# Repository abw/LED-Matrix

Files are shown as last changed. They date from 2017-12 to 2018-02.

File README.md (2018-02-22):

# LED-Matrix
This project contains design templates, schematics, PCB layouts and
other resources for the construction of an LED Matrix

Watch the YouTube video series:

* [Part 1](https://www.youtube.com/watch?v=AXzYg67qcFU)
* [Part 2](https://www.youtube.com/watch?v=oouwt-w1FjE)
* [Part 3](https://www.youtube.com/watch?v=P1SUvm24y38)
* [Part 4](https://www.youtube.com/watch?v=9LTRPMgsqeI)

The [documents](documents) directory contains plans, templates, cutting
guides, etc.

See the [hardware](hardware) directory for the
schematics and board designs for the [power distribution board](hardware/Power%20Board/v1.2)
and the main [control board](hardware/Control%20Board/v1.0).

The [arduino](arduino) directory contains the source code for Arduino firmware.
This includes the examples that are shown in part 4 of the video series.

The [sketchup](sketchup) directory contains a CAD design of the LED
Matrix created in Sketchup.

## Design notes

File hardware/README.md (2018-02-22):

# LED-Matrix Hardware
This directory contains the Eagle schematics, board designs and Gerber
files for the LED Matrix.

The [Power Board](Power%20Board/v1.2) is a power distribution module
that hosts 3 MP1584EN buck regulator modules.  These provide power for
the LED strips.

The [Control Board](Control%20Board/v1.0) is a board which can be used
as an all-in-one Arduino shield, or as a pair of mother/daughter boards.
It provides a connection to the Power Board to receive power and return
data for the LED strips.  It also has 4 connectors for push-button
switches with integrated LEDs in the bezel.

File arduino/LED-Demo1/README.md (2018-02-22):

# LED-Demo1

This is the first "proper" attempt at writing some pattern generation
firmware for the 24x18 LED Matrix.

At the time of writing (22th Feb 2018) this code is still very much a
work in progress.

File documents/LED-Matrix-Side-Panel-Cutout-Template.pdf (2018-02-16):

LED Matrix - Side Panel Cutout Template

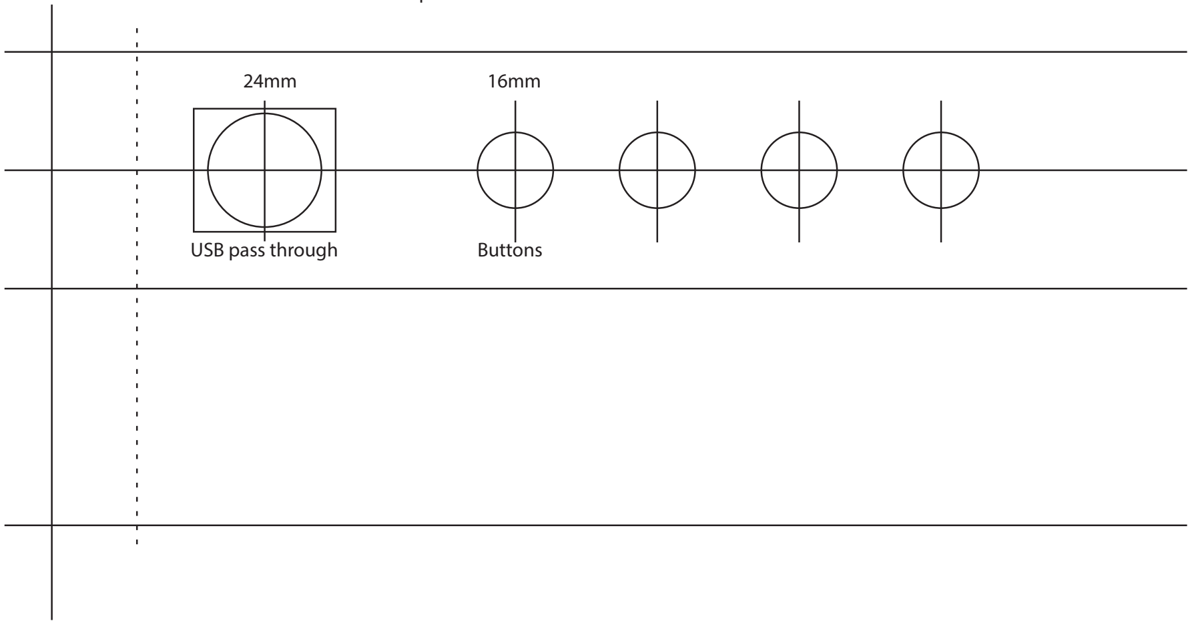
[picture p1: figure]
USB pass through; Buttons

Andy Wardley - December 2017

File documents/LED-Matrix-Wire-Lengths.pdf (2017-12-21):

### LED Matrix - wire lengths for connecting LED strips to power distribution boards

X | 100 | horizontal distance between connectors and power board
Y | 33.333 | vertical distance between each row of LEDs (30/m = 1000mm/30 = 33.333mm)
DY | 9 | vertical distance between connectors (9mm)
Margin | 20
| | Connectors for strips are labelled: A B C D E F with power board between C and D
A,F | 180.8325 | X + 2.5(Y - DY) + Margin
B,E | 156.4995 | X + 1.5(Y - DY) + Margin
C,D | 132.1665 | X + 0.5(Y - DY) + Margin

1

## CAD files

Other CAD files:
sketchup/LED-Matrix-case.skp

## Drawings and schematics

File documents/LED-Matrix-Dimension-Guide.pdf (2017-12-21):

## CUT-AWAY SIDE VIEW

## LED Matrix Dimension Guide

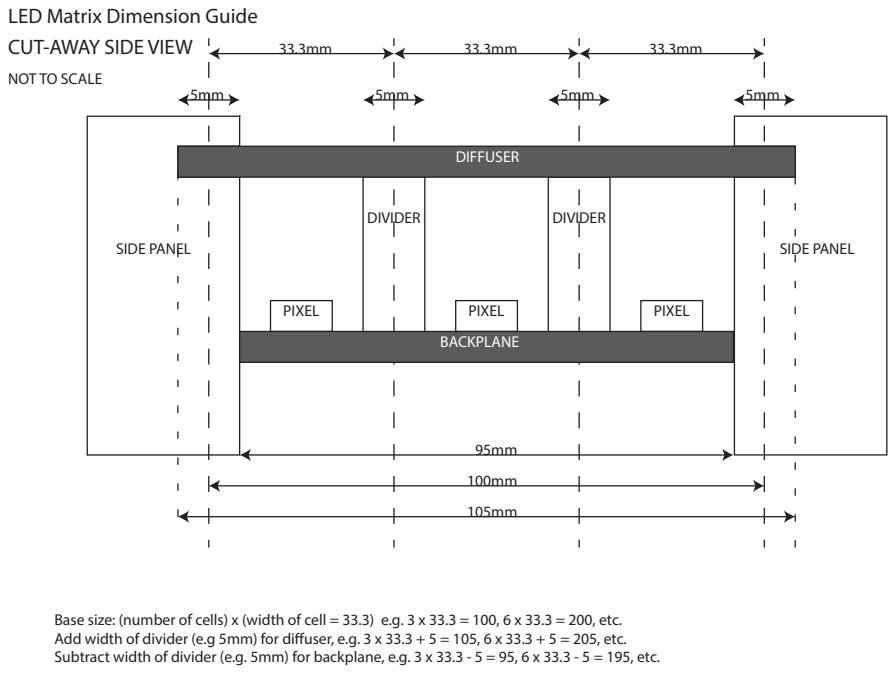
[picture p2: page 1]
BACKPLANE; DIFFUSER; SIDE PANEL; DIVIDER; PIXEL

NOT TO SCALE

Base size: (number of cells) x (width of cell = 33.3) e.g. 3 x 33.3 = 100, 6 x 33.3 = 200, etc.
Add width of divider (e.g 5mm) for diuser, e.g. 3 x 33.3 + 5 = 105, 6 x 33.3 + 5 = 205, etc.
Subtract width of divider (e.g. 5mm) for backplane, e.g. 3 x 33.3 - 5 = 95, 6 x 33.3 - 5 = 195, etc.

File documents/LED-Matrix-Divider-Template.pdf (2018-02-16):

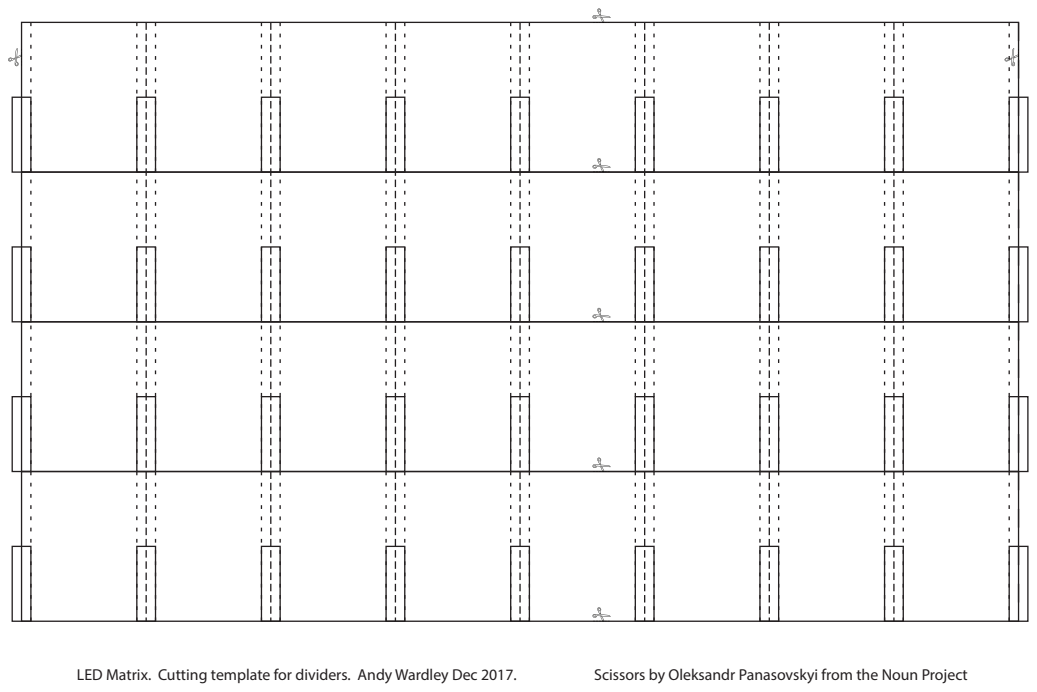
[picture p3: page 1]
LED Matrix. Cutting template for dividers. Andy Wardley Dec 2017.; Scissors by Oleksandr Panasovskyi from the Noun Project

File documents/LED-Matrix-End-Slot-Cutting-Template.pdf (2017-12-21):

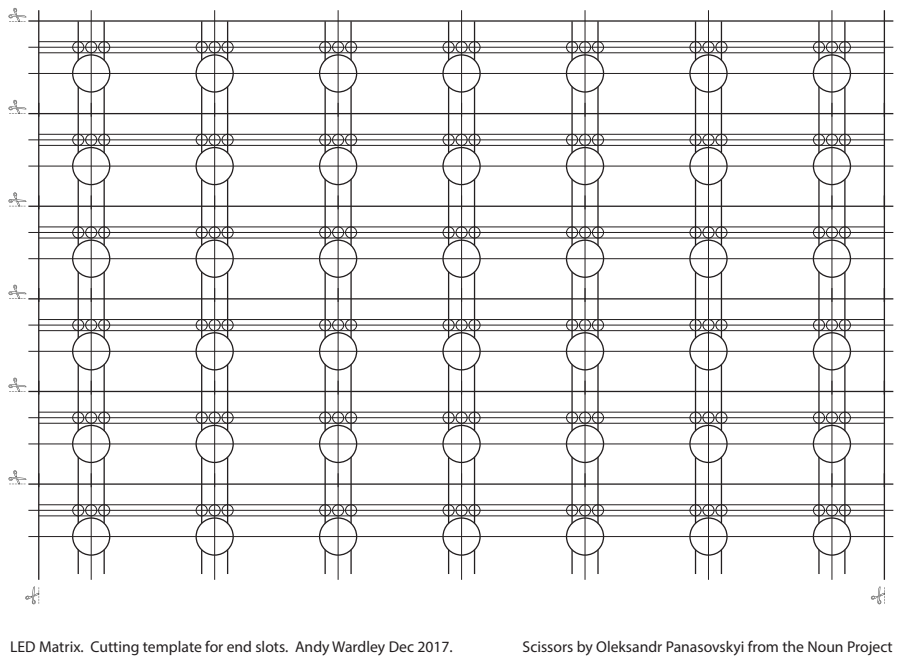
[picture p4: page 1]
LED Matrix. Cutting template for end slots. Andy Wardley Dec 2017.; Scissors by Oleksandr Panasovskyi from the Noun Project

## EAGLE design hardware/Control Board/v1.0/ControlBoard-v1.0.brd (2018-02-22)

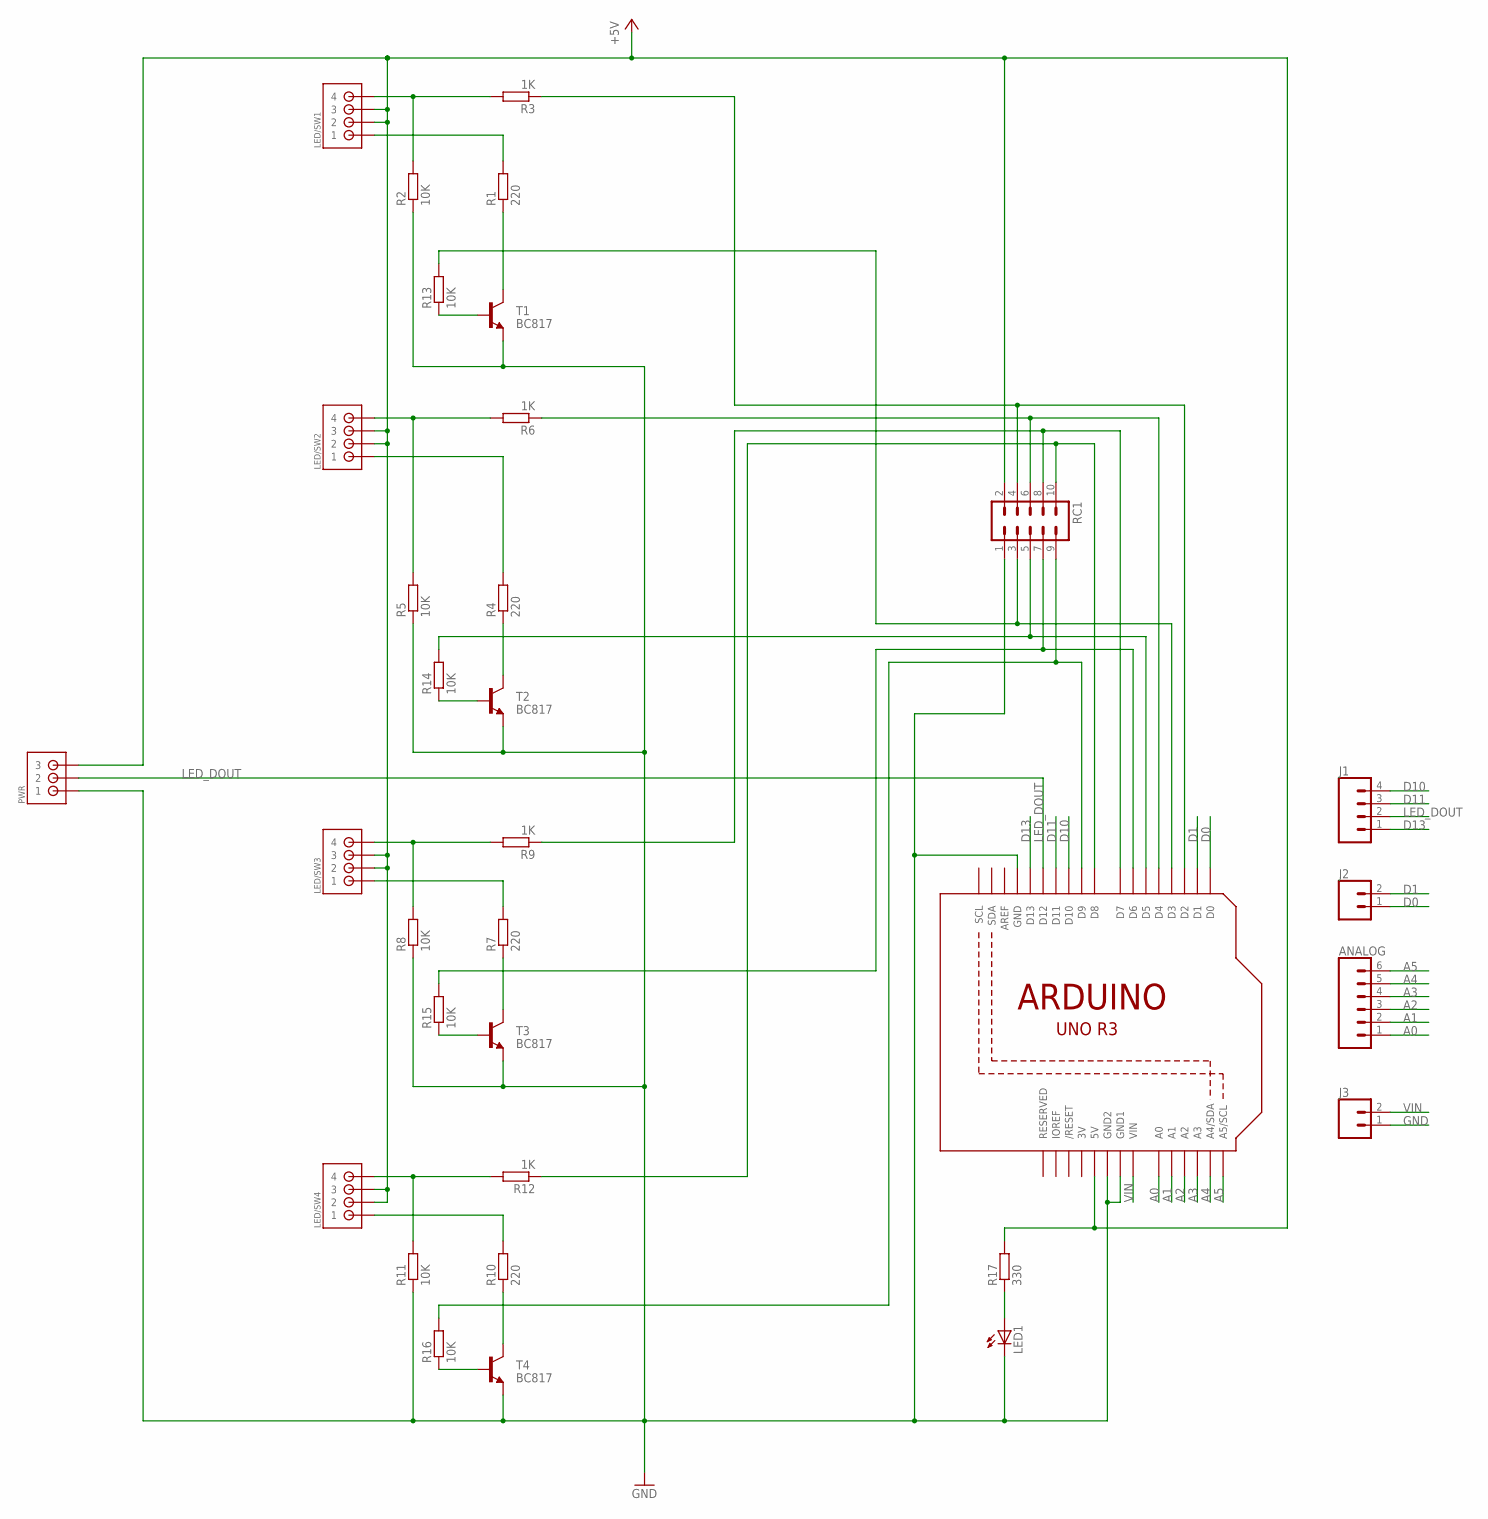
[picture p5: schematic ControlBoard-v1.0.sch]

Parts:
ANALOG: CONN_06SILK_FEMALE_PTH; 1X06
J1: CONN_04; 1X04
J2, J3: CONN_02; 1X02
LED1: LEDCHIPLED_0805; CHIPLED_0805
LED/SW1, LED/SW2, LED/SW3, LED/SW4: JST-XA-04-PIN; JST-XA-04
PWR: JST-XA-03-PIN; JST-XA-03
R1, R4, R7, R10: 220; R0805
R2, R5, R8, R11, R13, R14, R15, R16: 10K; R0805
R3, R6, R9, R12: 1K; R0805
R17: 330; R0805
RC1: ML10
T1, T2, T3, T4: BC817; SOT23
U1: ARDUINO-SHIELDLET; ARDUINOR3-PINS

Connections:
3V: U1.3V
+5V: LED/SW1.2, LED/SW1.3, LED/SW2.2, LED/SW2.3, LED/SW3.2, LED/SW3.3, LED/SW4.2, LED/SW4.3, PWR.3, R17.2, RC1.2, U1.5V
A0: ANALOG.1, U1.A0
A1: ANALOG.2, U1.A1
A2: ANALOG.3, U1.A2
A3: ANALOG.4, U1.A3
A4: ANALOG.5, U1.A4 (A4/SDA)
A5: ANALOG.6, U1.A5 (A5/SCL)
D0: J2.1, U1.D0
D1: J2.2, U1.D1
D10: J1.4, U1.D10
D11: J1.3, U1.D11
D13: J1.1, U1.D13
GND: J3.1, LED1.C, PWR.1, R2.1, R5.1, R8.1, R11.1, RC1.1, T1.2 (E), T2.2 (E), T3.2 (E), T4.2 (E), U1.GND, U1.GND1, U1.GND2
LED_DOUT: J1.2, PWR.2, U1.D12
unnamed: LED/SW1.1, R1.2
unnamed: R1.1, T1.3 (C)
unnamed: LED/SW1.4, R2.2, R3.2
unnamed: R3.1, RC1.4, U1.D2
unnamed: R13.1, T1.1 (B)
unnamed: LED/SW2.1, R4.2
unnamed: R4.1, T2.3 (C)
unnamed: LED/SW2.4, R5.2, R6.2
unnamed: R6.1, RC1.6, U1.D4
unnamed: R14.2, RC1.5, U1.D5
unnamed: LED/SW3.1, R7.2
unnamed: R7.1, T3.3 (C)
unnamed: LED/SW3.4, R8.2, R9.2
unnamed: R9.1, RC1.8, U1.D7
unnamed: R15.2, RC1.7, U1.D6
unnamed: LED/SW4.1, R10.2
unnamed: R10.1, T4.3 (C)
unnamed: LED/SW4.4, R11.2, R12.2
unnamed: R12.1, RC1.10, U1.D8
unnamed: R16.2, RC1.9, U1.D9
unnamed: R14.1, T2.1 (B)
unnamed: R15.1, T3.1 (B)
unnamed: R16.1, T4.1 (B)
unnamed: LED1.A, R17.1
unnamed: R13.2, RC1.3, U1.D3
VIN: J3.2, U1.VIN

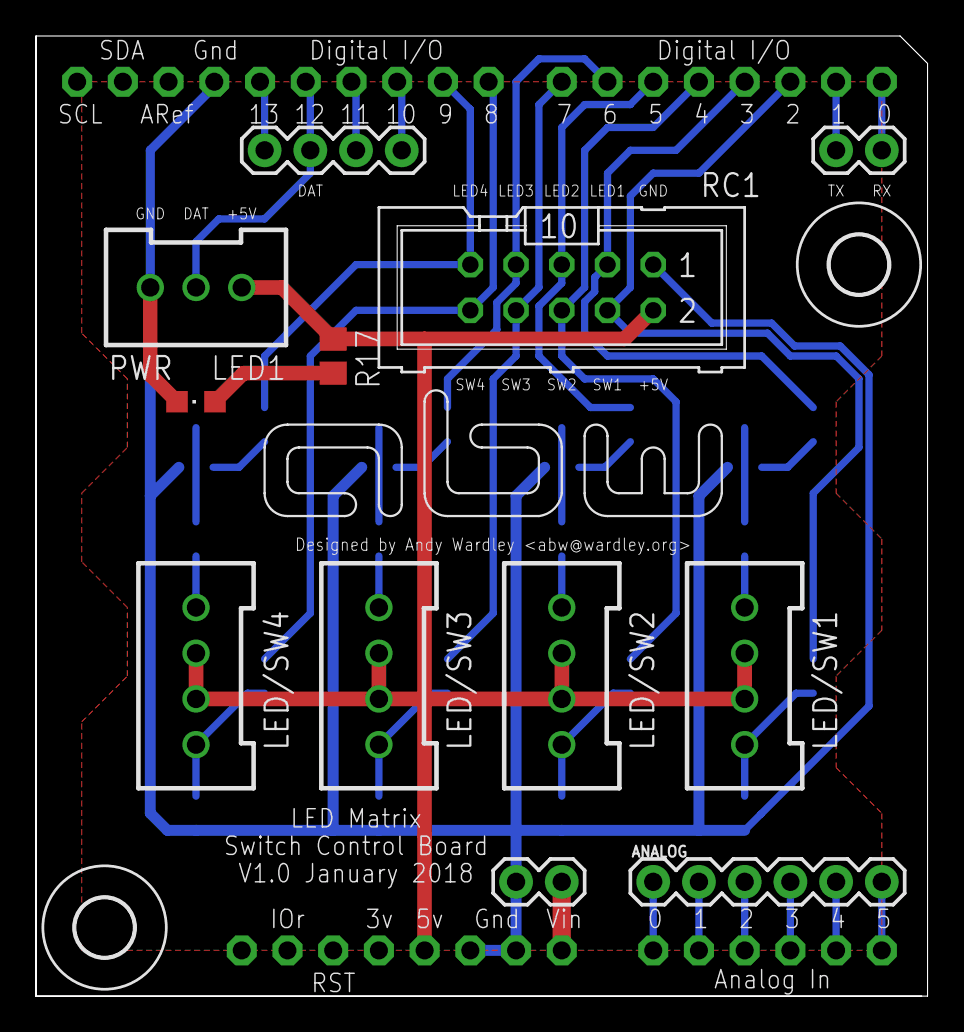
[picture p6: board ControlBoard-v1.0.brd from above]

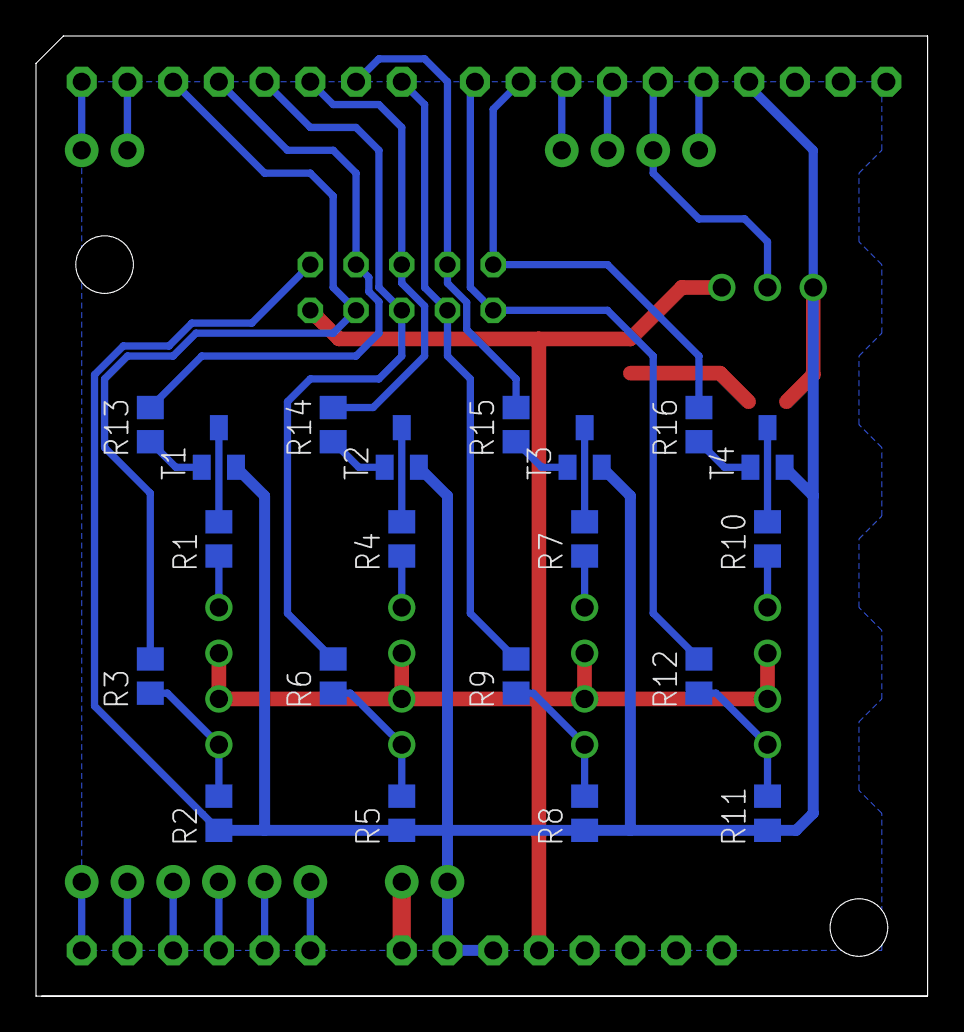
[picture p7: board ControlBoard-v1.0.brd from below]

Board: 2 copper layers, 49.5 x 53.3 mm, 36 parts (20 on the bottom side), 40 nets.

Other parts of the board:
U$2, U$3: 3,2
U$4: ABWLOGO-TINY

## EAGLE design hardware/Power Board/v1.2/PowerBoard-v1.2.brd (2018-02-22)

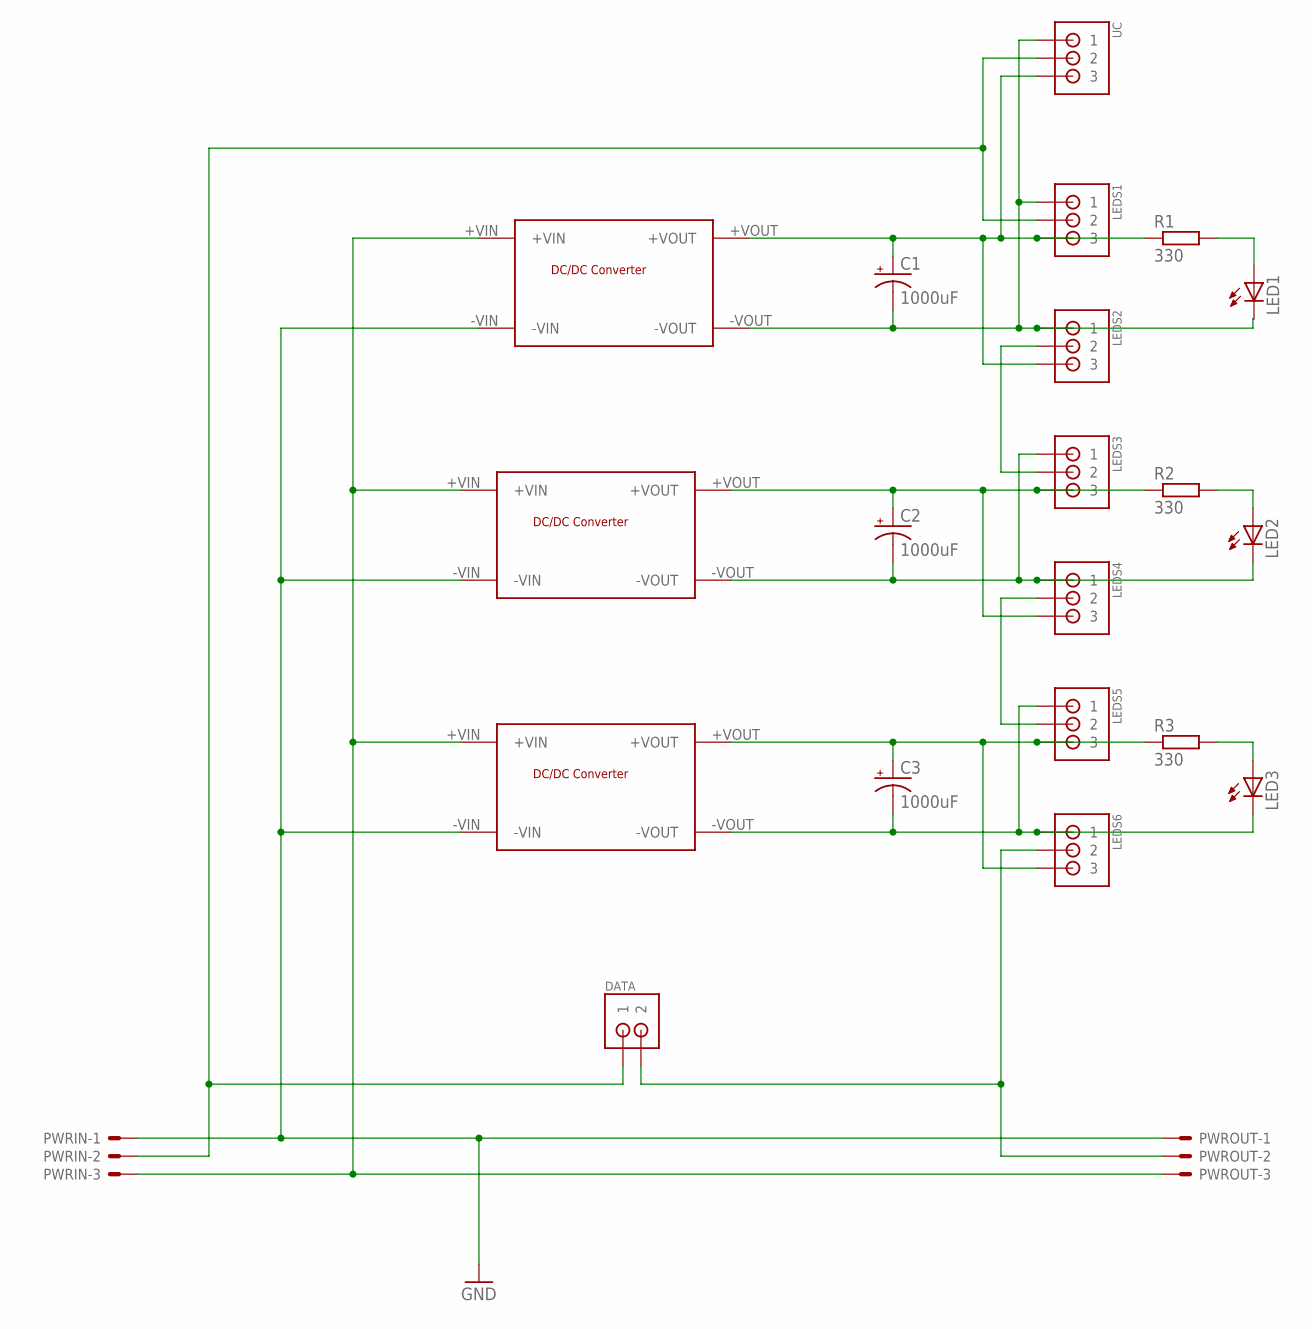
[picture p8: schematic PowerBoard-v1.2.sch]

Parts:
C1, C2, C3: 1000uF; CPOL-RADIAL-1000UF-25V
DATA: JST-XA-02-PIN; JST-XA-02
LED1, LED2, LED3: LEDCHIP-LED0805; CHIP-LED0805
LEDS1, LEDS2, LEDS3, LEDS4, LEDS5, LEDS6: JST-XA-03-PIN; JST-XA-03
PWRIN: KK-156-3
PWROUT: KK-156-3
R1, R2, R3: 330; M0805
U$1, U$2, U$3: DC-DC-CONVERTER; MP1584EN-BUCK-CONVERTER
UC: JST-XA-03-PIN; JST-XA-03

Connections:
DATIN: DATA.1, LEDS1.2, PWRIN.2, UC.2
DATOUT: DATA.2, LEDS6.2, PWROUT.2
GND: PWRIN.1, PWROUT.1, U$1.-VIN, U$2.-VIN, U$3.-VIN
GNDOUT1: C1.-, LED1.C, LEDS1.1, LEDS2.1, U$1.-VOUT, UC.1
GNDOUT2: C2.-, LED2.C, LEDS3.1, LEDS4.1, U$2.-VOUT
GNDOUT3: C3.-, LED3.C, LEDS5.1, LEDS6.1, U$3.-VOUT
unnamed: LED1.A, R1.2
unnamed: LED2.A, R2.2
unnamed: LEDS2.2, LEDS3.2
unnamed: LEDS4.2, LEDS5.2
unnamed: LED3.A, R3.2
VIN: PWRIN.3, PWROUT.3, U$1.+VIN, U$2.+VIN, U$3.+VIN
VOUT1: C1.+, LEDS1.3, LEDS2.3, R1.1, U$1.+VOUT, UC.3
VOUT2: C2.+, LEDS3.3, LEDS4.3, R2.1, U$2.+VOUT
VOUT3: C3.+, LEDS5.3, LEDS6.3, R3.1, U$3.+VOUT

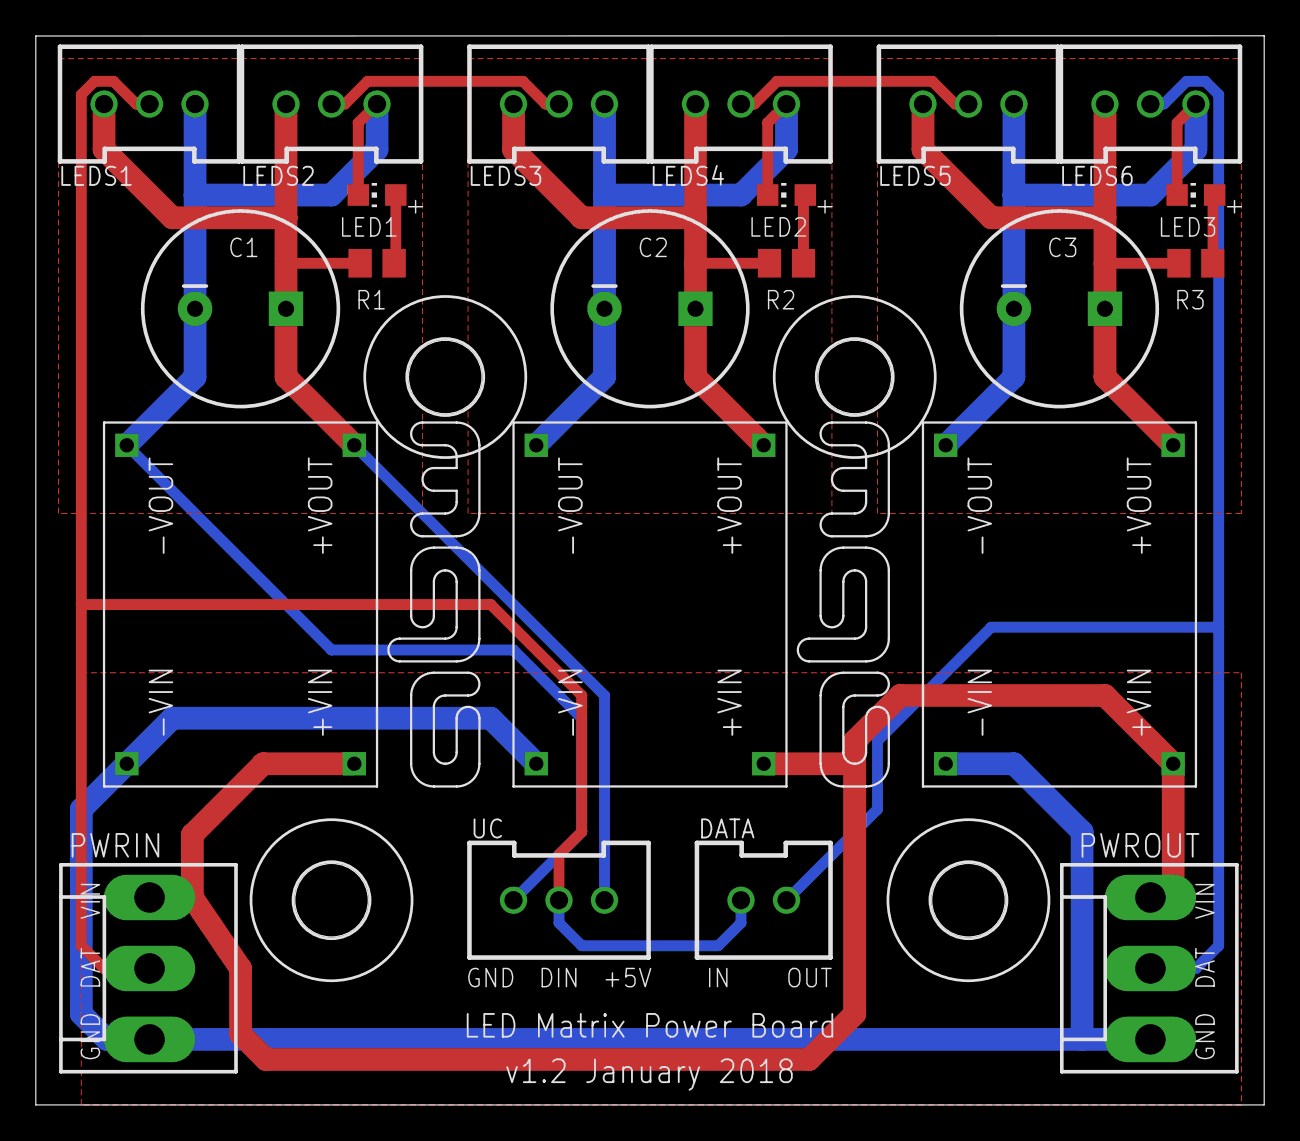
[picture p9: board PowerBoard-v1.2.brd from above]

Board: 2 copper layers, 68.6 x 59.7 mm, 29 parts (1 on the bottom side), 15 nets.

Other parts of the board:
U$4, U$5, U$6, U$7: 4,1
U$8: ABWLOGO-SMALL
U$9, U$10: ABWLOGO-MICRO

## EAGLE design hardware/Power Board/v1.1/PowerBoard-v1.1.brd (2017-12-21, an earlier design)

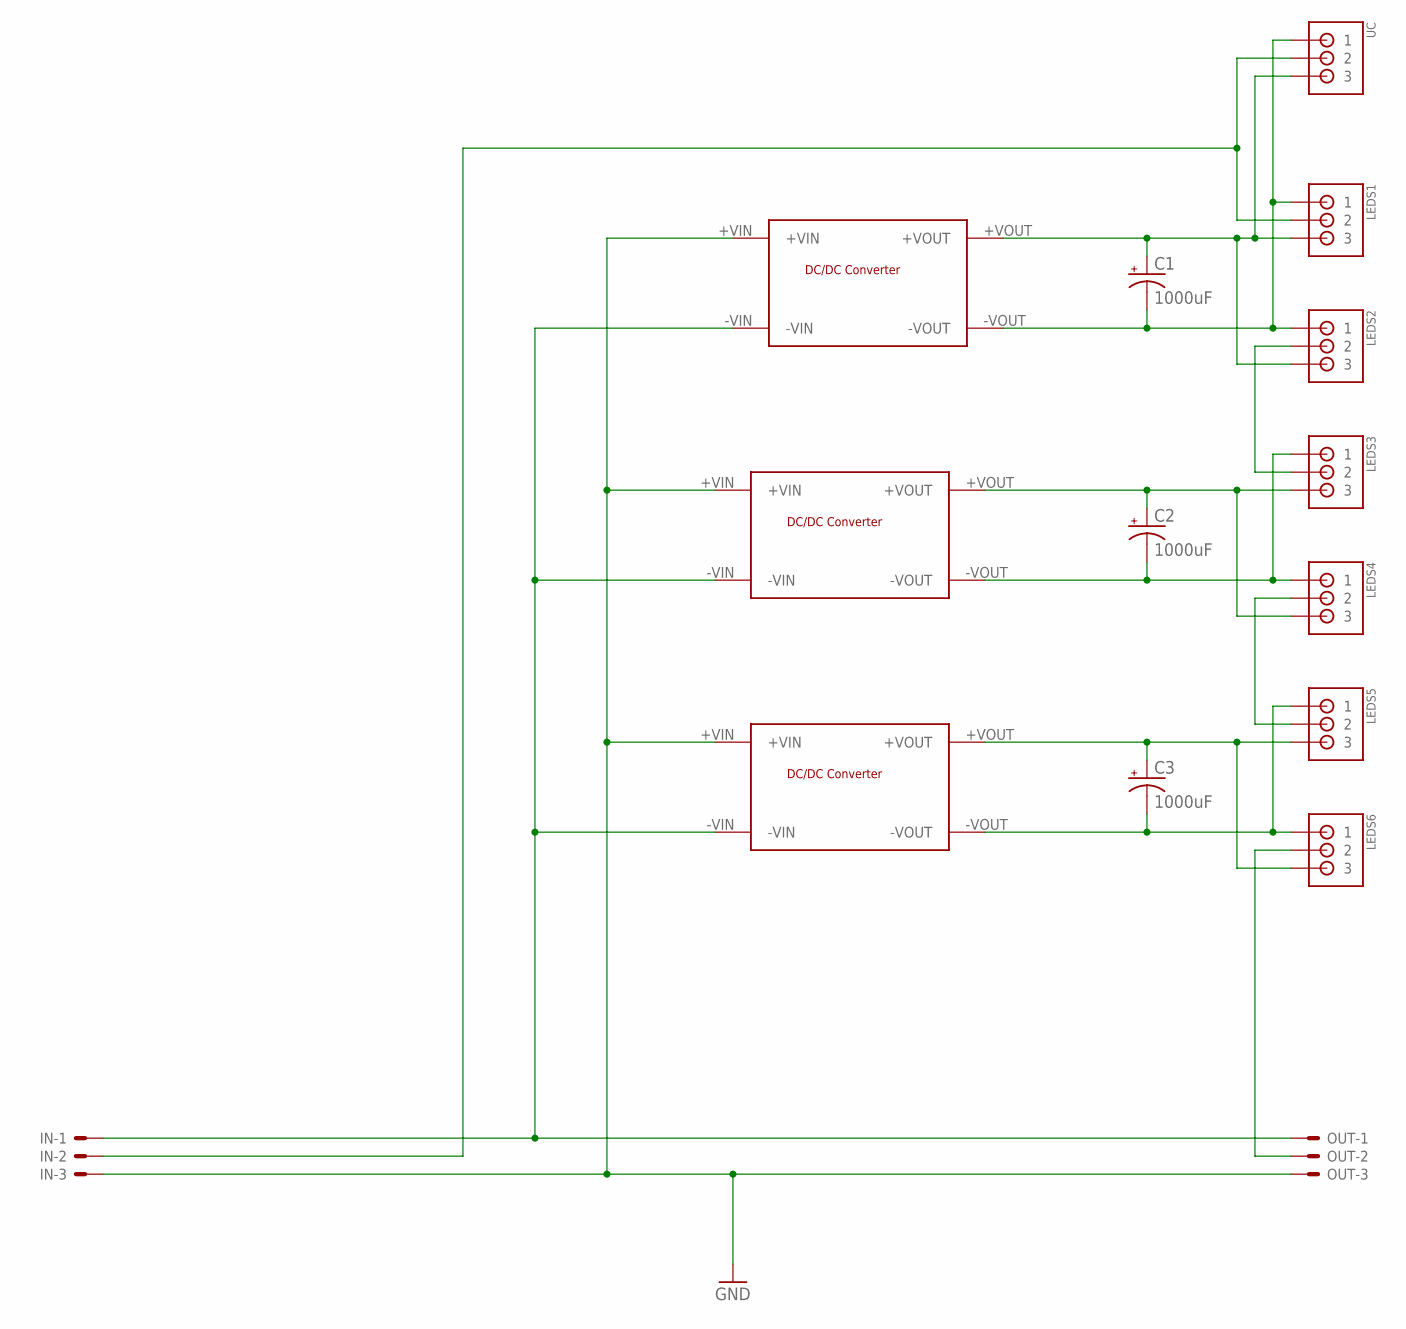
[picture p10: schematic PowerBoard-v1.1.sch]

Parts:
C1, C2, C3: 1000uF; CPOL-RADIAL-1000UF-25V
IN: 22-23-2031
LEDS1, LEDS2, LEDS3, LEDS4, LEDS5, LEDS6: JST-XA-03-PIN; JST-XA-03
OUT: 22-23-2031
U$1, U$2, U$3: DC-DC-CONVERTER; MP1584EN-BUCK-CONVERTER
UC: JST-XA-03-PIN; JST-XA-03

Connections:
GND: IN.3, OUT.3, U$1.+VIN, U$2.+VIN, U$3.+VIN
unnamed: IN.1, OUT.1, U$1.-VIN, U$2.-VIN, U$3.-VIN
unnamed: C1.-, LEDS1.1, LEDS2.1, U$1.-VOUT, UC.1
unnamed: C1.+, LEDS1.3, LEDS2.3, U$1.+VOUT, UC.3
unnamed: C2.+, LEDS3.3, LEDS4.3, U$2.+VOUT
unnamed: C2.-, LEDS3.1, LEDS4.1, U$2.-VOUT
unnamed: C3.+, LEDS5.3, LEDS6.3, U$3.+VOUT
unnamed: C3.-, LEDS5.1, LEDS6.1, U$3.-VOUT
unnamed: IN.2, LEDS1.2, UC.2
unnamed: LEDS2.2, LEDS3.2
unnamed: LEDS4.2, LEDS5.2
unnamed: LEDS6.2, OUT.2

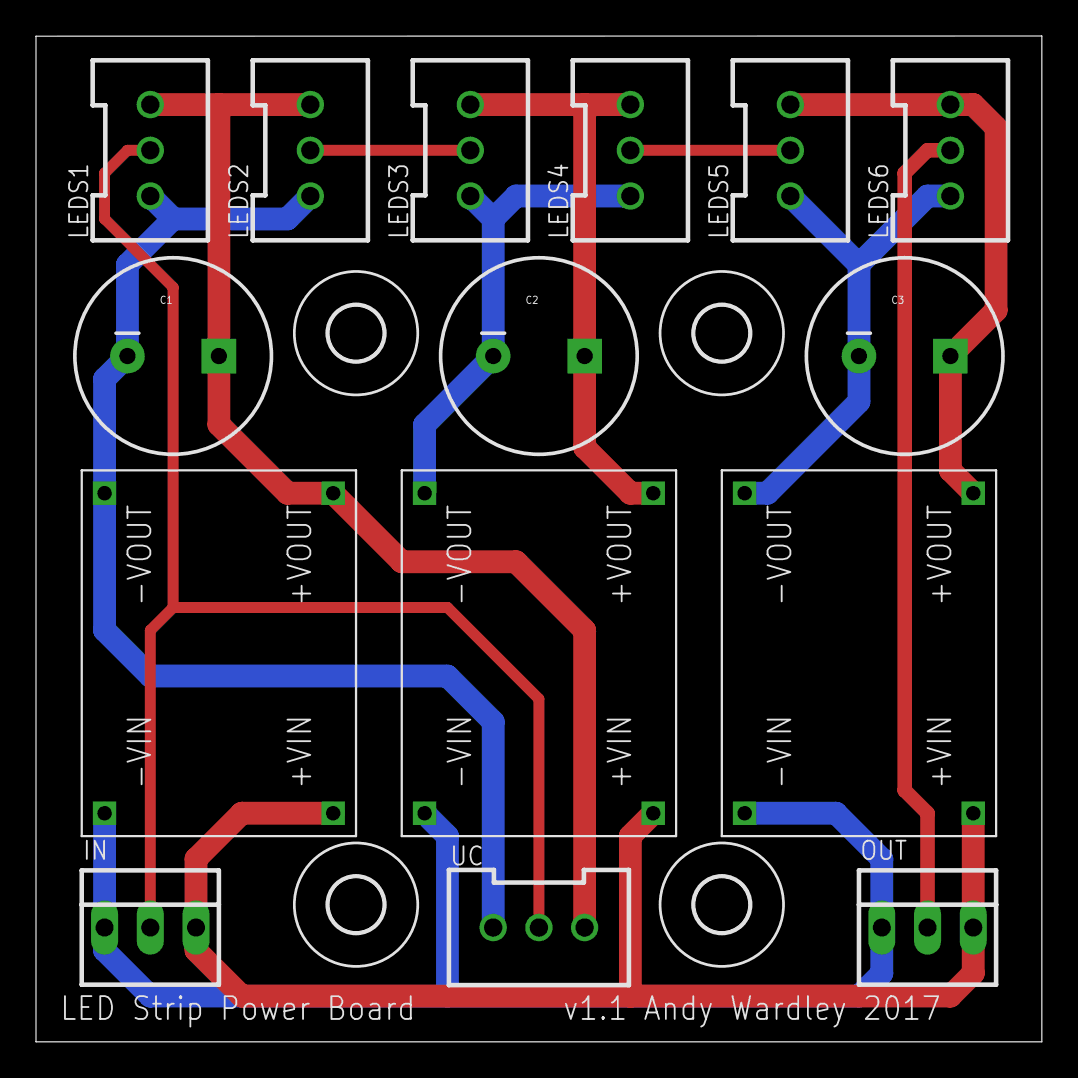
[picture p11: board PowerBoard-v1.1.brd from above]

Board: 2 copper layers, 55.9 x 55.9 mm, 19 parts (0 on the bottom side), 12 nets.

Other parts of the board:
U$4, U$5, U$6, U$7: 3,0

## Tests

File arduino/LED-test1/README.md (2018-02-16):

# LED-test1

This is a simple test to check that all LEDs are working.

This can be seen running at the end of the second video on the
construction of the backplane:

[Andy's Shed - Led Matrix Build - Part 2](https://www.youtube.com/watch?v=oouwt-w1FjE)

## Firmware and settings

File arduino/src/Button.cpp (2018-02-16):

#include "Button.hpp"

Button::Button(
    unsigned int swpin,
    unsigned int ledpin,
    double brightness,
    double phase,
    bool active,
    ButtonHandler onPress,
    ButtonHandler onRelease
) {
    _swpin = swpin;
    _ledpin = ledpin;
    _onPress = onPress;
    _onRelease = onRelease;
    _debouncer = Bounce();
    _debouncer.attach(_swpin);
    _debouncer.interval(DebounceInterval);
    _pulse.setAmplitude(brightness);
    _pulse.setPhase(phase);
    pinMode(_swpin, INPUT);
    pinMode(_ledpin, OUTPUT);
    if (active) {
        activate();
    }
    else {
        deactivate();
    }
}

bool Button::active() {
    return _active;
}

void Button::activate() {
    _active = true;
    _pulse.throb();
}

void Button::deactivate() {
    _active = false;
    _pulse.off();
    analogWrite(_ledpin, 0);
}

unsigned int Button::swpin() {
    return _swpin;
}

unsigned int Button::ledpin() {
    return _ledpin;
}

void Button::setHandlers(
    ButtonHandler press,
    ButtonHandler release
) {
    onPress(press);
    onRelease(release);
}

void Button::onPress(ButtonHandler press) {
    _onPress = press;
}

void Button::onRelease(ButtonHandler release) {
    _onRelease = release;
}

void Button::clearHandlers() {
    setHandlers(NULL, NULL);
}

bool Button::check() {
    if (_active && _debouncer.update()) {
        if (_debouncer.fell()) {
            // falling edge, i.e. button released
            released();
        }
        else {
            // must be a rising edge, i.e. button pressed
            pressed();
        }

        return true;
    }

    return false;
}

void Button::pulse(double time) {
    if (_active) {
        unsigned int val = 255 * _pulse.pulse(time);
        analogWrite(_ledpin, val);
        //printf("pulse: %d\n", val);
    }
}

void Button::pressed() {
    _pulse.flash();

    if (_onPress) {
        _onPress(this);
    }
}

void Button::released() {
    _pulse.throb();

    if (_onRelease) {
        _onRelease(this);
    }
}

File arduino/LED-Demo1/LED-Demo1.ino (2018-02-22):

#include <FastLED.h>
#include "LEDMatrix.hpp"
//#include "Point.hpp"
#include "Cursor.hpp"
#include "Button.hpp"
#include "SignWriter.hpp"

#define DEBUG_SERIAL 1

// Define the LED matrix as (width, height)
const unsigned int ledPin  = 12;
const unsigned int width   = 24;
const unsigned int height  = 18;
const unsigned int numLeds = width * height;
CRGB leds[width * height];
LEDMatrix matrix(leds, width, height, BottomRight, RowsSnake);

// Define the four buttons with integrated LEDs, each has a switch pin
// (input) and LED pin (output).  The latter (i.e. 3, 5, 6 and 9) must
// be PWM capable.  The third argument is the overall brightness from 0
// to 1.  The fourth argument is phase (0-1).  Set to the same value
// to have the LEDs flash in phase or to different values for out of phase.
// The fifth argument indicates if the button is active.
Button redButton(2, 3, 0.7, 0, false);
Button greenButton(4, 5, 0.6, 0, true);
Button blueButton(7, 6, 1.0, 0, false);  // yes, these pins are supposed to be out of order!
Button whiteButton(8, 9, 1.0, 0, false);

// create a list of pointers to the buttons so we can iterate over them
const int numButtons = 4;
Button *buttons[numButtons] = {
    &redButton, &greenButton, &blueButton, &whiteButton
};

// a cursor is a snake-like path that moves around the array
Cursor cursor(
    &matrix,
    0, 8,               // start position x, y
    31, 11,             // velocity vector x, y
    Reflect, Reflect,   // edge handling x, y
    48                  // trail length
);
//Cursor cursor(
//    &matrix,
//    11, 3,         // start position x, y
//    -12, 0,        // velocity vector x, y
//    Wrap, Wrap,    // edge handling x, y
//    1              // trail length
//);
// a trailblazer is a bit of code to render the cursor trail to the LEDs
TrailBlazer blazer(&matrix);
// a signwriter is a subclass of TrailBlazer to test text rendering
//SignWriter writer(&matrix);

// I can't think of a better name for this variable that determines the
// maximum speed of the cursor.  The maximum range of movement (pixels
// per second) is this factor multipled by the width and/or height as
// appropriate.  This is then shift down half way to give a negative
// or positive range of half that value.  So for a 24 x 18 array with
// maxFactor set to 6, the maximum range would be -72 to +72 (3 x 24 = 72)
// in the x direction and -54 to +54 (3 x 18)  in the y direction.
const unsigned int maxFactor = 6;

// global state variables
unsigned long start;      // milliseconds start time
double time;              // floating point seconds elapsed
bool running = false;

// function prototypes;
void startup(Button *b);
unsigned int checkButtons();
void pulseButtons(double time);
void blackout();
void pushRed(Button *b);
void pushGreen(Button *b);
void pushBlue(Button *b);
void pushWhite(Button *b);

void setup() {
    // initialise FastLED
    pinMode(ledPin, OUTPUT);
    FastLED.addLeds<NEOPIXEL, ledPin>(leds, numLeds);

    // blackout the LEDs in case any have retained their memory
    blackout();

    // In my implementation the unit goes into standby mode when first
    // turned on with only the green button active (see fifth arguments
    // where buttons are created above).  When the green button is pressed
    // the other buttons are activated and the LED patterns display.
    greenButton.onPress(startup);

#if DEBUG_SERIAL
    Serial.begin(9600);
    Serial.println("setup");
#endif
}

void startup(Button *b) {
    // activate the three buttons that are inactive
    redButton.activate();
    blueButton.activate();
    whiteButton.activate();

    // register handlers for button pushed (just test code for now)
    redButton.onPress(pushRed);
    greenButton.onPress(pushGreen);
    blueButton.onPress(pushBlue);
    whiteButton.onPress(pushWhite);

    running = true;
    start = millis();
    time = 0;

#if DEBUG_SERIAL
    Serial.println("startup");
#endif
}

void loop() {
    unsigned long now = millis() - start;
    time = (double) now / 1000;

    if (running) {
        // animate here
        cursor.move(time);
        cursor.blaze(&blazer);
        //cursor.blaze(&writer);
        FastLED.show();
    }

    checkButtons();
    pulseButtons(time);
}


unsigned int checkButtons() {
    int updated = 0;

    for (int i = 0; i < numButtons; i++) {
        updated += buttons[i]->check();
    }
    return updated;
}

void pulseButtons(double time) {
    for (int i = 0; i < numButtons; i++) {
        buttons[i]->pulse(time);
    }
}

void blackout() {
    matrix.screenRGB(0, 0, 0);
    FastLED.show();
}

void pushRed(Button *b) {
#if DEBUG_SERIAL
    Serial.println("Push Red");
#endif
    cursor.changeDirection(-12, 0);
}

void pushGreen(Button *b) {
#if DEBUG_SERIAL
    Serial.println("Push Green");
#endif
    cursor.changeDirection(0, 9);
}

void pushBlue(Button *b) {
#if DEBUG_SERIAL
    Serial.println("Push Blue");
#endif
    cursor.changeDirection(5, 3);
}

void pushWhite(Button *b) {
#if DEBUG_SERIAL
    Serial.println("Push White");
#endif
    cursor.changeDirection(
        (double) (rand() % (width  * maxFactor)) - (width  * maxFactor / 2),
        (double) (rand() % (height * maxFactor)) - (height * maxFactor / 2)
    );
}

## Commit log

2017-12-21 Added documents, power board design and test firmware
    [PowerBoard.brd, PowerBoard.sch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]
2018-02-13 Added LED-Demo1 files
2018-02-16 Added sketchup model
    [LED-Matrix-case.skp]
2018-02-16 Added arduino demo code
2018-02-21 Changed LEDMatrix to return CRGB reference
2018-02-22 Added schematics and board layout for new power module (v1.2)
    [PowerBoard-v1.1.brd, PowerBoard-v1.1.sch, PowerBoard-v1.2.brd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]
2018-02-22 Added files for Control Board
    [ControlBoard-v1.0.brd, ControlBoard-v1.0.sch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]

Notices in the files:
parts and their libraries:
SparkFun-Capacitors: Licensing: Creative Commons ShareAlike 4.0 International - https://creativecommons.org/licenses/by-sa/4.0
